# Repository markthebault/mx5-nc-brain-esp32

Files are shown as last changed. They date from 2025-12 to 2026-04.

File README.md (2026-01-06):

# MX5 NC Brain ESP32

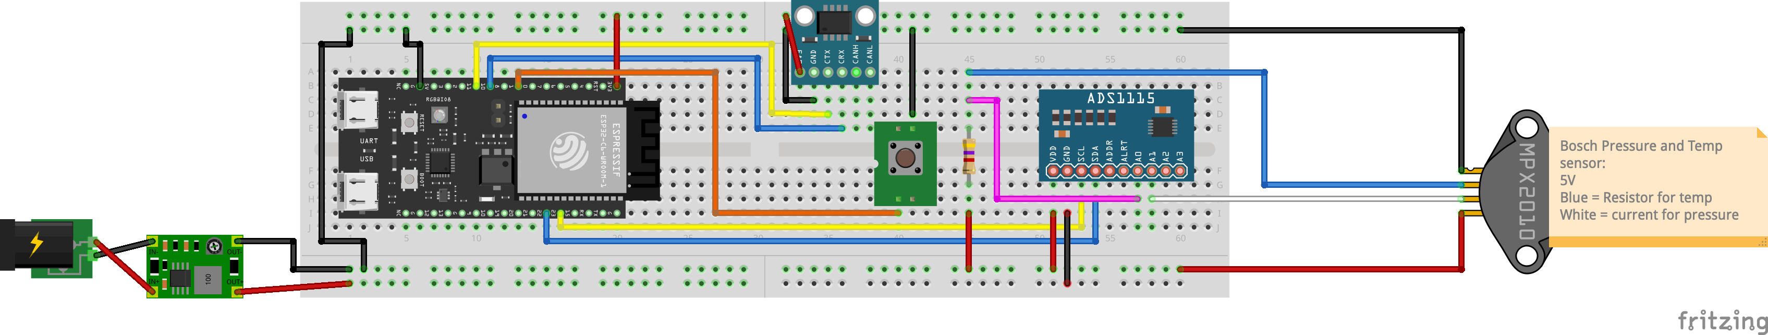
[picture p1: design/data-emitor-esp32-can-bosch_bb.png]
MX-5 NC Telemetry


ESP32-based telemetry system for Mazda MX5 NC using ESP-NOW wireless protocol for real-time vehicle data broadcasting.

## Overview

This is a telemetry transmitter (master) that reads vehicle data from multiple sources and broadcasts it wirelessly using the ESP-NOW protocol. The system collects data from:
- **CAN Bus**: Reading vehicle data directly from the car's CAN network
- **Physical Sensors**: Oil pressure and temperature sensors connected to analog inputs
- **Future ESP-NOW Nodes**: Other ESP32 devices can send additional sensor data to this master unit

The system uses a broadcast architecture, allowing multiple receivers to listen to the same data stream without requiring a Wi-Fi router.

## Features

- **Multi-Source Data Collection**:
  - CAN bus integration for reading vehicle network data
  - Direct analog sensor inputs (oil pressure, oil temperature)
  - ESP-NOW receiver capability for data from remote sensor nodes
- **Wireless Broadcasting**:
  - Low-latency ESP-NOW wireless communication
  - Broadcast architecture supporting multiple receivers
  - No Wi-Fi router required
- **Performance**:
  - Configurable update rate (default: 10Hz)
  - Low power consumption
  - Real-time data aggregation

## Telemetry Data

The system tracks and transmits the following metrics:

### From CAN Bus
- **Water Temperature** (°C) - Engine coolant temperature
- **Engine RPM** - Engine speed
- **Brake Pressure** (bar) - Brake system pressure
- **Brake Percentage** (%) - Brake pedal position
- **Throttle Position** (%) - Throttle body position
- **Vehicle Speed** (km/h) - Vehicle speed from ABS/ECU
- **Accelerator Position** (%) - Accelerator pedal position

### From Physical Sensors
- **Oil Temperature** (°C) - Direct sensor reading
- **Oil Pressure** (bar) - Direct sensor reading

### From Remote ESP-NOW Nodes (Future)
- Additional sensor data from distributed nodes throughout the vehicle

## Hardware Requirements

### Core Components
- ESP32 development board (with CAN bus support recommended)
- CAN bus transceiver module (e.g., MCP2515, TJA1050, or ESP32 with built-in TWAI)
- Power supply (12V vehicle power to 5V/3.3V regulation recommended)

### Sensors
- Oil pressure sensor (analog output)
- Oil temperature sensor (analog output)
- Additional sensors as needed (expandable)

### Optional
- Additional ESP32 nodes for remote sensor data collection via ESP-NOW

**Note**: Receivers can be any ESP32-based device capable of receiving ESP-NOW broadcasts. Receiver implementation is separate from this transmitter project.

## Software Dependencies

### Libraries Required
- `ESP32_NOW` - ESP-NOW protocol implementation
- `WiFi` - Wi-Fi management
- `esp_mac` - MAC address utilities
- CAN bus library (depending on hardware):
  - `ESP32-TWAI-CAN` - For ESP32 built-in TWAI controller
  - `mcp2515` - For MCP2515 CAN controller modules
  - `arduino-CAN` - Generic CAN library

### Installation
Install via Arduino IDE Library Manager or PlatformIO:
```
ESP32_NOW
ESP32-TWAI-CAN (or appropriate CAN library for your hardware)
```

## Configuration

### Wi-Fi Channel
Set the ESP-NOW channel (default: Channel 6). Any receivers must use the same channel:
```cpp
#define ESPNOW_WIFI_CHANNEL 6
```

### Telemetry Structure
The telemetry data structure broadcasts the following format. Receivers must implement matching structure:
```cpp
typedef struct __attribute__((packed)) {
  float oilTemp;
  float waterTemp;
  uint32_t engineRPM;
  float oilPressure;
  float brakePressure;
  int brakePercent;
  float throttlePos;
  float speed;
  float accelPos;
} TelemetryData;
```

## Usage

### Setup
1. **CAN Bus Connection**:
   - Connect CAN transceiver to ESP32 (TX/RX pins or SPI for MCP2515)
   - Connect CAN-H and CAN-L to vehicle's OBD-II port or direct CAN bus tap
   - Configure CAN bus speed to match vehicle (typically 500 kbps for Mazda)

2. **Sensor Connections**:
   - Connect oil pressure sensor to analog input pin
   - Connect oil temperature sensor to analog input pin
   - Ensure sensors output 0-3.3V (use voltage dividers if necessary)

3. **Software Configuration**:
   - Update CAN message IDs for your specific vehicle
   - Configure sensor reading and mapping logic in `loop()` function
   - Adjust ADC resolution if needed (default: 12-bit)
   - Set sensor calibration values for your specific sensors

4. **Upload**:
   - Upload `mth-car-brain-esp32.ino` to ESP32

### Monitoring
Serial output provides debugging information including:
- Broadcast success/failure status
- Current telemetry values
- Connection status

### Integration
Receivers can be built using any ESP32 device configured to listen on the same ESP-NOW channel. The broadcast architecture allows multiple receivers to monitor the same data stream simultaneously.

## Project Structure

```
mx5-nc-brain-esp32/
├── mth-car-brain-esp32.ino          # Main transmitter sketch
└── test-on-device/                   # Test and development files
```

## Customization

### Adding New Sensors
1. Update `TelemetryData` structure to include new fields
2. Add sensor reading code in `loop()`
3. Update sensor mapping and calibration values
4. Ensure any receivers also update their structure to match

### Adjusting Update Rate
Change delay in `loop()`:
```cpp
delay(100); // 10Hz (100ms between transmissions)
delay(50);  // 20Hz (50ms between transmissions)
delay(200); // 5Hz (200ms between transmissions)
```

### Sensor Calibration
Adjust the mapping values in `loop()` to match your specific sensors:
```cpp
myData.oilTemp = map(sensorValue, 0, 3330, 0, 170); // Adjust min/max values
```

## Troubleshooting

### CAN Bus Issues
- Verify CAN-H and CAN-L connections are correct (not swapped)
- Check CAN bus termination resistors (120Ω at each end)
- Confirm CAN bus speed matches vehicle (typically 500 kbps)
- Ensure vehicle ignition is on for CAN bus activity
- Use CAN bus analyzer tool to verify message traffic
- Check for proper ground connection between ESP32 and vehicle

### Transmitter Not Broadcasting
- Check serial output for "Failed to initialize ESP-NOW"
- Verify Wi-Fi channel configuration
- Ensure ESP32 board is properly powered
- Confirm ESP32_NOW library is correctly installed

### Sensor Reading Issues
- Verify sensor connections to analog pins
- Check ADC resolution setting (default: 12-bit)
- Validate sensor voltage ranges match ESP32 input (0-3.3V)
- Use serial output to monitor raw sensor values
- Check sensor power supply voltage
- Verify sensor ground connection

### Communication Issues
- Ensure Wi-Fi channel is not congested
- Check for interference from other 2.4GHz devices
- Verify adequate power supply to ESP32
- For remote ESP-NOW nodes, check distance and line-of-sight

## Performance

- **Update Rate**: 10Hz (configurable)
- **Range**: ~200m line-of-sight (ESP-NOW typical range)
- **Latency**: <10ms typical
- **Data Size**: 36 bytes per transmission

## Future Enhancements

This project is designed to be expandable with the following planned additions:

### Planned Sensors
- Additional temperature sensors (transmission, differential, brakes)
- G-force/accelerometer sensors
- GPS module for location and speed data
- Fuel level and consumption monitoring
- Tire pressure monitoring

### Distributed Sensor Network
- Multiple ESP32 nodes positioned throughout the vehicle
- Each node collecting local sensor data
- Nodes transmit data to the main brain unit via ESP-NOW
- Main unit aggregates and rebroadcasts complete telemetry package

### Architecture Benefits
- **Scalability**: Easy to add new sensors without rewiring
- **Modularity**: Independent sensor nodes can be added/removed
- **Reliability**: Distributed processing reduces single point of failure
- **Flexibility**: Sensor nodes can be positioned optimally without distance constraints

## License

This project is provided as-is for personal use.

## Contributing

Feel free to submit issues or pull requests for improvements.

## Acknowledgments

Built for Mazda MX5 NC telemetry monitoring using ESP32 platform and ESP-NOW protocol.

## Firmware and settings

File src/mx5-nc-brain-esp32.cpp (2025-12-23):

#include <Arduino.h>
#include <Wire.h>
#include <Adafruit_ADS1X15.h>
#include <math.h>
#include "ESP32_NOW.h"
#include "WiFi.h"
#include <esp_mac.h>

// --- Debug Configuration ---
#define DEBUG 1  // Set to 1 to enable debug output, 0 to disable

#if DEBUG
  #define DEBUG_BEGIN(baud) Serial.begin(baud)
  #define DEBUG_PRINT(x) Serial.print(x)
  #define DEBUG_PRINTLN(x) Serial.println(x)
  #define DEBUG_PRINTF(...) Serial.printf(__VA_ARGS__)
#else
  #define DEBUG_BEGIN(baud)
  #define DEBUG_PRINT(x)
  #define DEBUG_PRINTLN(x)
  #define DEBUG_PRINTF(...)
#endif

// --- Configuration ---
namespace Config {
    // Hardware Pins for ESP32-C6
    constexpr uint8_t I2C_SDA = 21;
    constexpr uint8_t I2C_SCL = 22;

    // --- VOLTAGE DIVIDER SETTINGS ---
    /** R1 is the fixed pull-up resistor (Updated to 2k). */
    constexpr float R_PULLUP = 2000.0; 
    
    /** Measured Supply Voltage: Updated to your measured 5.02V for precision. */
    constexpr float V_SUPPLY = 5.02;

    // --- TEMPERATURE SENSOR CONSTANTS (NTC) ---
    /** BETA: Optimized for 70°C to 150°C range. */
    constexpr float NTC_BETA     = 3654.55; 
    /** R_NOMINAL: Resistance of the sensor at 20°C. */
    constexpr float NTC_R_NOM    = 2480.0;
    /** NTC_T_NOM: 20°C in Kelvin. */
    constexpr float NTC_T_NOM    = 293.15; 

    // --- PRESSURE SENSOR CONSTANTS ---
    constexpr float PRESS_C0     = 0.1;
    constexpr float PRESS_C1     = 0.0008;

    // --- PRESSURE CALIBRATION ---
    /** Initial pressure offset for auto-zero calibration. */
    constexpr float PRESSURE_OFFSET = 0.0;
}

/* --- Telemetry Structure --- */
typedef struct __attribute__((packed)) {
  float oilTemp;
  float waterTemp;
  uint32_t engineRPM;
  float oilPressure;
  float brakePressure;
  int brakePercent;
  float throttlePos;
  float speed;
  float accelPos;
} TelemetryData;

// Create global instances
Adafruit_ADS1115 ads;
TelemetryData myData;
float pressureOffset = Config::PRESSURE_OFFSET; // Auto-zero value initialized from config

/* --- ESP-NOW Configuration --- */
#define ESPNOW_WIFI_CHANNEL 6

class ESP_NOW_Broadcast_Peer : public ESP_NOW_Peer {
public:
  ESP_NOW_Broadcast_Peer(uint8_t channel, wifi_interface_t iface, const uint8_t *lmk) 
    : ESP_NOW_Peer(ESP_NOW.BROADCAST_ADDR, channel, iface, lmk) {}

  ~ESP_NOW_Broadcast_Peer() { remove(); }

  bool begin() {
    if (!ESP_NOW.begin() || !add()) return false;
    return true;
  }

  bool send_message(const uint8_t *data, size_t len) {
    return send(data, len);
  }
};

ESP_NOW_Broadcast_Peer broadcast_peer(ESPNOW_WIFI_CHANNEL, WIFI_IF_STA, nullptr);

/**
 * Converts ADC voltage to Temperature in Celsius
 */
double calculateTemperature(double v_measured) {
    if (v_measured >= Config::V_SUPPLY || v_measured <= 0.01) return -99.9; 
    double r_ntc = (v_measured * Config::R_PULLUP) / (Config::V_SUPPLY - v_measured);
    double steinhart = log(r_ntc / Config::NTC_R_NOM);
    steinhart /= Config::NTC_BETA;
    steinhart += 1.0 / Config::NTC_T_NOM;
    return (1.0 / steinhart) - 273.15; 
}

/**
 * Converts ADC voltage to Pressure in Bars (Raw)
 */
float calculatePressureBarRaw(float v_measured) {
    float v_clamped = constrain(v_measured, 0.5f, 4.5f);
    float pressureKPa = ((v_clamped / Config::V_SUPPLY) - Config::PRESS_C0) / Config::PRESS_C1;
    return pressureKPa / 100.0f;
}

void setup() {
    DEBUG_BEGIN(115200);
    delay(1000);
    DEBUG_PRINTLN("Initializing Combined Telemetry System...");

    Wire.begin(Config::I2C_SDA, Config::I2C_SCL);
    ads.setGain(GAIN_TWOTHIRDS);  // 2/3x gain +/- 6.144V  1 bit = 3mV      0.1875mV (default)
    // ads.setGain(GAIN_ONE);        // 1x gain   +/- 4.096V  1 bit = 2mV      0.125mV
    // ads.setGain(GAIN_TWO);        // 2x gain   +/- 2.048V  1 bit = 1mV      0.0625mV
    // ads.setGain(GAIN_FOUR);       // 4x gain   +/- 1.024V  1 bit = 0.5mV    0.03125mV
    // ads.setGain(GAIN_EIGHT);      // 8x gain   +/- 0.512V  1 bit = 0.25mV   0.015625mV
    // ads.setGain(GAIN_SIXTEEN);    // 16x gain  +/- 0.256V  1 bit = 0.125mV  0.0078125mV

    if (!ads.begin()) {
        DEBUG_PRINTLN("Critical Error: ADS1115 not found!");
        while (1) delay(10);
    }

    // --- Auto-Zero Calibration ---
    DEBUG_PRINTLN("Calibrating Pressure Offset (Keep Engine OFF)...");
    float sum = 0;
    for(int i = 0; i < 20; i++) {
        sum += calculatePressureBarRaw(ads.computeVolts(ads.readADC_SingleEnded(1)));
        delay(50);
    }
    pressureOffset = sum / 20.0;
    DEBUG_PRINTF("Calibration Done. Offset: %.2f Bar\n", pressureOffset);

    // --- Wi-Fi / ESP-NOW Setup ---
    WiFi.mode(WIFI_STA);
    WiFi.setChannel(ESPNOW_WIFI_CHANNEL);
    while (!WiFi.STA.started()) { delay(100); }

    if (!broadcast_peer.begin()) {
        DEBUG_PRINTLN("ESP-NOW Init Failed!");
        delay(5000);
        ESP.restart();
    }
    DEBUG_PRINTLN("Telemetry Master Online.");
}

void loop() {
    int16_t adc[4];
    float volts[4];

    // 1. Read ADS1115 channels
    for (int i = 0; i < 4; i++) {
        adc[i] = ads.readADC_SingleEnded(i);
        volts[i] = ads.computeVolts(adc[i]);
    }

    // 2. Process data
    float rawOilPress = calculatePressureBarRaw(volts[1]);
    
    myData.oilTemp     = (float)calculateTemperature(volts[0]); 
    myData.oilPressure = rawOilPress - pressureOffset;
    if (myData.oilPressure < 0) myData.oilPressure = 0; // Floor to zero

    // Example/Static Data
    myData.waterTemp     = 92.5;   
    myData.engineRPM     = 3500;   
    myData.brakePressure = 0.0;
    myData.brakePercent  = 0;
    myData.throttlePos   = 25.5;
    myData.speed         = 110.2;
    myData.accelPos      = 20.0;

    // 3. Print Local Debug Info (Raw vs Corrected)
    DEBUG_PRINTLN("-----------------------------------------------------------");
    for (int i = 0; i < 4; i++) {
        DEBUG_PRINTF("AIN%d: %-6d | %5.3f V\n", i, adc[i], volts[i]);
    }
    DEBUG_PRINTF("TEMP:  Raw: %5.2f °C | Corrected (5.02V): %5.2f °C\n", calculateTemperature(volts[0]), myData.oilTemp);
    DEBUG_PRINTF("PRESS: Raw: %5.2f Bar | Corrected (Zeroed): %5.2f Bar\n", rawOilPress, myData.oilPressure);

    // 4. Broadcast via ESP-NOW
    bool success = broadcast_peer.send_message((uint8_t *)&myData, sizeof(myData));
    DEBUG_PRINTF("ESP-NOW Broadcast: %s\n", success ? "Success" : "Failed");

    
    
    

    // SLEEP CYCLE
    delay(200); // Slightly slower loop for readability

    // Not working
    // // 5. Enter Light Sleep
    // // This stops the CPU and lowers radio power until the timer hits
    // if(esp_sleep_enable_timer_wakeup(200 * 1000) == ESP_OK) {
    //     DEBUG_PRINTLN("Entering Light Sleep for 200ms...");
    //     esp_light_sleep_start();
    // } else {
    //     DEBUG_PRINTLN("Failed to set wakeup timer!");
    // }
}

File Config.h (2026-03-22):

#ifndef CONFIG_H
#define CONFIG_H

#include "driver/twai.h"
#include <Arduino.h>

/**
 * @file Config.h
 * @brief Central configuration file for MX5 NC Brain ESP32 telemetry system
 *
 * Hardware: ESP32-C6 DevKit
 * Peripherals: ADS1115 ADC, TWAI (CAN Bus), ESP-NOW
 */

// =============================================================================
// GENERAL CONFIGURATION
// =============================================================================
namespace GeneralConfig {
// --- Hardware Pins - ESP32-C6 ---
// I2C SDA (Serial Data) pin - connects to ADS1115 SDA
constexpr uint8_t I2C_SDA = 22;

// I2C SCL (Serial Clock) pin - connects to ADS1115 SCL
constexpr uint8_t I2C_SCL = 23;

// --- Serial Debug ---
// Serial baud rate for debug output (115200 is standard for ESP32)
constexpr uint32_t SERIAL_BAUD_RATE = 115200;

// --- ESP-NOW Wireless ---
// WiFi channel for ESP-NOW communication (1-13, must match on all devices)
constexpr uint8_t ESPNOW_WIFI_CHANNEL = 6;

// --- Timing ---
// Main loop delay in milliseconds (controls telemetry update rate)
// 500ms = 2 updates per second, 100ms = 10 updates per second, etc.
constexpr int MAIN_LOOP_DELAY_MS = 25;

// --- Button Configuration ---
// GPIO pin for push button input
constexpr uint8_t BUTTON_PIN = 1;

// Button debounce time in milliseconds
constexpr uint8_t BUTTON_DEBOUNCE_MS = 50;

// --- Potentiometer Configuration ---
// GPIO pin for potentiometer (luminosity control)
constexpr uint8_t POT_PIN = 2;

// Potentiometer voltage range (connected to 3.3V)
constexpr float POT_V_MAX = 2.8;

// Luminosity range mapping (0V → 10%, 3.3V → 100%)
constexpr uint8_t LUMINOSITY_MIN = 10;
constexpr uint8_t LUMINOSITY_MAX = 100;

// Startup luminosity override: force 100% for this duration (ms)
constexpr unsigned long LUMINOSITY_STARTUP_MS = 10000;
} // namespace GeneralConfig

// =============================================================================
// WEB SERVER CONFIGURATION (WiFi AP + Dashboard)
// =============================================================================
namespace WebServerConfig {
// WiFi Access Point credentials
constexpr const char *AP_SSID = "MX5_Dashboard";
constexpr const char *AP_PASSWORD = "laepaithio565"; // Min 8 characters

// HTTP server port
constexpr uint16_t PORT = 80;

// Dashboard data refresh interval in milliseconds
constexpr uint16_t REFRESH_INTERVAL_MS = 500;

// FreeRTOS task stack size in bytes
constexpr uint16_t TASK_STACK_SIZE = 8192;
} // namespace WebServerConfig

// =============================================================================
// CAN BUS CONFIGURATION (TWAI - Two-Wire Automotive Interface)
// =============================================================================
namespace CANConfig {
// GPIO pin for CAN TX (Transmit) - connects to CAN transceiver TX pin
constexpr gpio_num_t TX_GPIO = (gpio_num_t)11;

// GPIO pin for CAN RX (Receive) - connects to CAN transceiver RX pin
constexpr gpio_num_t RX_GPIO = (gpio_num_t)10;

// CAN bus speed in bits per second (500kbps is standard for automotive)
constexpr uint32_t SPEED = 500000;
} // namespace CANConfig

// =============================================================================
// ADS1115 ADC CONFIGURATION (Analog-to-Digital Converter)
// =============================================================================
namespace ADS1115Config {
// --- Channel Assignments ---
// Channel 0 (A0) - Oil Temperature Sensor (NTC)
constexpr uint8_t CH_OIL_TEMP = 0;

// Channel 1 (A1) - Oil Pressure Sensor (Linear)
constexpr uint8_t CH_OIL_PRESS = 1;

// Channel 3 (A3) - Supply Voltage Monitoring
constexpr uint8_t CH_SUPPLY_VOLTAGE = 3;

// --- Voltage Divider Settings (for NTC thermistor) ---
// Fixed pull-up resistor value in Ohms (connects between V_SUPPLY and NTC)
// Used in voltage divider: V_SUPPLY --- R_PULLUP --- [measurement point] ---
// NTC --- GND
constexpr float R_PULLUP = 4700.0;

// Measured supply voltage in Volts (calibrated for accuracy)
// Should be measured with multimeter for best temperature readings
constexpr float V_SUPPLY = 5.02;

// --- NTC Thermistor Configuration (Oil Temperature Sensor) ---
// BETA coefficient for NTC thermistor (material constant)
// Optimized for 70°C to 150°C range typical of engine oil temperature
constexpr float NTC_BETA = 3654.55;

// Nominal resistance of NTC at reference temperature (20°C) in Ohms
// Specific to the NTC thermistor model being used
constexpr float NTC_R_NOM = 2480.0;

// Nominal temperature in Kelvin (20°C = 293.15K)
// Reference temperature for NTC_R_NOM resistance value
constexpr float NTC_T_NOM = 293.15;

// --- Pressure Sensor Configuration (Oil Pressure Sensor) ---
// Pressure sensor linear equation: Pressure(kPa) = ((V / V_SUPPLY) - C0) / C1
// Y-intercept constant for voltage-to-pressure conversion
constexpr float PRESS_C0 = 0.1;

// Slope constant for voltage-to-pressure conversion (kPa per volt ratio)
constexpr float PRESS_C1 = 0.0008;
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

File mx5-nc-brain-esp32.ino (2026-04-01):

/**
 * @file mx5-nc-brain-esp32.ino
 * @brief Main telemetry system for Mazda MX5 NC
 *
 * This system reads sensor data (oil temp, oil pressure) via ADS1115,
 * receives CAN bus data (RPM, speed, throttle, etc.) from the vehicle ECU,
 * and broadcasts all telemetry via ESP-NOW to remote displays.
 *
 * Hardware: ESP32-C6
 * Author: Mark Thebault
 * Date: 2025
 */

#include <Arduino.h>
#include <Wire.h>
#include <Adafruit_ADS1X15.h>

// Project headers
#include "Config.h"
#include "Debug.h"
#include "TelemetryData.h"
#include "SensorUtils.h"
#include "CANBus.h"
#include "ESPNowBroadcast.h"
#include "Buttons.h"
#include "DashboardServer.h"

// --- Global Objects ---
Adafruit_ADS1115 ads;
TelemetryData myData;
DashboardServer::DashboardData dashboardData;
ESP_NOW_Broadcast_Peer broadcast_peer(GeneralConfig::ESPNOW_WIFI_CHANNEL, WIFI_IF_STA, nullptr);

// --- Calibration Data ---
float pressureOffset = ADS1115Config::PRESSURE_OFFSET;

// --- EMA Smoothing State ---
float smoothedPressure = 0.0;
float smoothedTemperature = 0.0;
bool firstReading = true;

void setup() {
    DEBUG_BEGIN(GeneralConfig::SERIAL_BAUD_RATE);
    delay(1000);
    DEBUG_PRINTLN("===========================================");
    DEBUG_PRINTLN("  MX5 NC Telemetry System - Initializing");
    DEBUG_PRINTLN("===========================================");

    // --- I2C and ADS1115 Setup ---
    DEBUG_PRINTLN("Initializing I2C and ADS1115...");
    Wire.begin(GeneralConfig::I2C_SDA, GeneralConfig::I2C_SCL);

    // Configure ADC gain
    // NOTE: Keep all gain options below for reference - DO NOT REMOVE
    ads.setGain(GAIN_TWOTHIRDS);  // 2/3x gain +/- 6.144V  1 bit = 3mV      0.1875mV (default)
    // ads.setGain(GAIN_ONE);        // 1x gain   +/- 4.096V  1 bit = 2mV      0.125mV
    // ads.setGain(GAIN_TWO);        // 2x gain   +/- 2.048V  1 bit = 1mV      0.0625mV
    // ads.setGain(GAIN_FOUR);       // 4x gain   +/- 1.024V  1 bit = 0.5mV    0.03125mV
    // ads.setGain(GAIN_EIGHT);      // 8x gain   +/- 0.512V  1 bit = 0.25mV   0.015625mV
    // ads.setGain(GAIN_SIXTEEN);    // 16x gain  +/- 0.256V  1 bit = 0.125mV  0.0078125mV

    if (!ads.begin()) {
        DEBUG_PRINTLN("CRITICAL ERROR: ADS1115 not found!");
        while (1) delay(10);
    }
    DEBUG_PRINTLN("ADS1115 initialized successfully.");

    // --- Auto-Zero Calibration for Pressure Sensor ---
    // Disabled: calibration zeros out pressure if engine is already running on ESP32 restart
    // pressureOffset = SensorUtils::calibratePressureOffset(ads, 1);

    // --- Wi-Fi / ESP-NOW Setup ---
    if (!ESPNowBroadcast::init(broadcast_peer)) {
        DEBUG_PRINTLN("ESP-NOW initialization failed! Restarting...");
        delay(5000);
        ESP.restart();
    }

    // --- Dashboard Web Server Setup ---
    DashboardServer::init();
    DashboardServer::startTask(&myData, &dashboardData);

    // --- CAN Bus Setup ---
    CANBus::init();
    CANBus::startReceiveTask(&myData);

    // --- Button Setup ---
    Buttons::init();
    Buttons::startTask(&myData);

    // --- Potentiometer Setup ---
    DEBUG_PRINTLN("Configuring potentiometer (luminosity control)...");
    pinMode(GeneralConfig::POT_PIN, INPUT);
    analogSetAttenuation(ADC_11db);  // Set ADC range to 0-3.3V

    // --- Initialize test data for debugging ---
    myData.engineRPM     = 3666;
    myData.brakePressure = 5.0;
    myData.brakePercent  = 0;
    myData.throttlePos   = 25.5;
    myData.speed         = 110.2;
    myData.accelPos      = 20.0;
    myData.gaugeType     = GAUGE_NORMAL;  // Start with normal gauge mode
    myData.luminosity    = 100;           // Will be controlled by potentiometer

    DEBUG_PRINTLN("===========================================");
    DEBUG_PRINTLN("  Telemetry Master Online");
    DEBUG_PRINTLN("===========================================");
}

void loop() {
    // --- 1. Read ADS1115 Channels ---
    int16_t adc[4];
    float volts[4];

    for (int i = 0; i < 4; i++) {
        adc[i] = ads.readADC_SingleEnded(i);
        volts[i] = ads.computeVolts(adc[i]);
    }

    // Use measured supply voltage from designated channel
    float realVcc = volts[ADS1115Config::CH_SUPPLY_VOLTAGE];
    
    // Fallback if realVcc is strangely low (e.g. not connected)
    if (realVcc < 3.0) {
        realVcc = ADS1115Config::V_SUPPLY;
    }

    // --- 2. Process Sensor Data ---
    // Oil Temperature
    float rawTemp = (float)SensorUtils::calculateTemperature(volts[ADS1115Config::CH_OIL_TEMP], realVcc);

    // Oil Pressure
    float rawOilPress = SensorUtils::calculatePressureBarRaw(volts[ADS1115Config::CH_OIL_PRESS], realVcc);

    // Seed EMA on first reading to avoid ramping from zero
    if (firstReading) {
        smoothedTemperature = rawTemp;
        smoothedPressure = rawOilPress;
        firstReading = false;
    }

    // Apply EMA smoothing
    smoothedTemperature = ADS1115Config::TEMPERATURE_EMA_ALPHA * rawTemp
                        + (1.0f - ADS1115Config::TEMPERATURE_EMA_ALPHA) * smoothedTemperature;
    smoothedPressure = ADS1115Config::PRESSURE_EMA_ALPHA * rawOilPress
                     + (1.0f - ADS1115Config::PRESSURE_EMA_ALPHA) * smoothedPressure;

    myData.oilTemp = smoothedTemperature;
    myData.oilPressure = (smoothedPressure > 0) ? smoothedPressure : 0;
    dashboardData.ain2Voltage = volts[2];

    // Water Temperature - Now received from CAN bus (ID 0x240)
    // myData.waterTemp is updated by CANBus::receiveTask() in CANBus.cpp

    // --- 3. Read Potentiometer and Update Luminosity ---
    if (millis() < GeneralConfig::LUMINOSITY_STARTUP_MS) {
        myData.luminosity = GeneralConfig::LUMINOSITY_MAX;
    } else {
        int potRaw = analogRead(GeneralConfig::POT_PIN);
        DEBUG_PRINTF("POT Val MTH Temp:   %d °C\n", potRaw);
        float potVoltage = ((float)potRaw) / 1000.0;
        float maxPotVoltage = GeneralConfig::POT_V_MAX * 1000.0;

        // Map voltage to luminosity: 0V → 10%, 3.3V → 100%
        int lum = (uint8_t)map(potRaw, 0, maxPotVoltage,
                                GeneralConfig::LUMINOSITY_MIN,
                                GeneralConfig::LUMINOSITY_MAX);

        myData.luminosity = constrain(lum, GeneralConfig::LUMINOSITY_MIN, GeneralConfig::LUMINOSITY_MAX);
    }
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

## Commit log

2025-12-21 add test for ads1115 and bosh sensor
2025-12-21 incorporate data from pressure sensor from ADS board
2025-12-23 Not working with platform io
    [backup.ino, mth-car-brain-test-receiver-c3oled043.ino, mx5-nc-brain-esp32.ino]
2025-12-25 extract button for racing mode
2026-01-01 update esp32 with sender and water temp now on the sender
2026-01-06 Add new design
    [data-emitor-esp32-can-bosch.fzz]
2026-01-06 Change pins to make board easier to build
2026-03-21 comment out the calibration because if the ESP32 restarts during engine running in will see wrong values
    [mx5-nc-brain-esp32.ino]
2026-03-22 feat: Define explicit ADS1115 channels and remove pressure calibration constants from configuration. (UNTESTED)
